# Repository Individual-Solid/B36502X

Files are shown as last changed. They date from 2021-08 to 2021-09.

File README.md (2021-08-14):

# BE6502X-SBC

## Overview
The BE6502X-SBC is an extensible single board computer, based on the "Hello World"
video tutorial by Ben Eater, and the "Potporri" computer design by Garth Wilson.

The computer features a W65c02 8-bit microprocessor running at 1Mhz, 32kb static 
RAM, 32kb EEPROM, two 8-bit GPIO ports, an onboard power supervisor, and a 40-pin
expansion bus.

The computer is "software compatible" with the programs Ben Eater builds in his
Youtube series. 

### Major Differences from the Ben Eater 6502 reference schematic
- Pull-up resistors on all active-low input signals (/NMI, /BE, etc...)
- Proper debounced reset pushbutton and power-on-reset circuit.
- Barrel jack 5v power connector, power LED, reset LED, SYNC LED, and switch.
- All 16 GPIO and 4 Control signals from the VIA are exposed through two
  14-pin shrouded pin IDC headers, CA2 also has an onboard LED.
- LCD, push-buttons, and 8-bit LED output are moved to an expansion board.
- Selector for 65c22 VIAs IRQ pin connection to processor /IRQ or /NMI

### Major Differences from the Garth Wilson 6502 reference schematic
- Clock option chosen is the Can Oscillator. Reset circuit chosen is DS1813.
- Because of these choices, an 74HC00 can be used for address decoding instead 
  of the '132
- Permanently configured for the WDC65c02 processor, 28C256 EEPROM.

## IO Ports
There are two onboard 8-bit IO ports connected to a W65c22S. Each port has an additional
two control lines. Each port has a 14-pin IDC male socket with the following pinout.
|Func|Pin#|Pin#|Func|
|----|-|-|---|
|GND|1|2|5V|
|Px0|3|4|Px1|
|Px2|5|6|Px3|
|Px4|7|8|Px5|
|Px6|9|10|Px7|
|Cx1|11|12|Cx2|
|5V|13|14|GND|

CA2 has an onboard indicator LED, but the pin can easily be repurposed.

## Bus

The BE6502X family sports a 40-pin extension bus. This bus is hardware compatible 
with RC2014 backplanes, although pin assignment is different. There's an existing 
small ecosystem of boards using the "RC6502" bus layout, but I invented my own 
think that felt natural to me. The original RC2014 bus has a lot of Z80/8080 
exclusive signals.

|Pin|BE6502X|RC6502|RC2014|Notes (primarily differences from RC6502)|
|-----|---|---|---|-----|
| 1|A15|A15|A15||
| 2|A14|A14|A14||
| 3|A13|A13|A13||
| 4|A12|A12|A12||
| 5|A11|A11|A11||
| 6|A10|A10|A10||
| 7|A9|A9|A9||
| 8|A8|A8|A8||
| 9|A7|A7|A7||
|10|A6|A6|A6||
|11|A5|A5|A5||
|12|A4|A4|A4||
|13|A3|A3|A3||
|14|A2|A2|A2||
|15|A1|A1|A1||
|16|A0|A0|A0||
|17|GND|GND|GND||
|18|VCC|VCC|VCC||
|19|/MLB|PHI2O|/M1|See CLK for why it's not PHI2O. 6502 has no /M1. This could be SYNC, but /MLB is more interesting for DMA|
|20|/RESET|/RESET|/RESET||
|21|CLK|PHI0I|CLK|Using PHI1 in and PHI2 out is not supported for the new W65c22 chips used in the Eater kit. Just using PHI2 as CLK opens up an additional signal.|
|22|/IRQ|/IRQ|/INT||
|23|/BE|PHI1I (but really,EX0)|/MREQ|Dedicated /BE line for DMA|
|24|RWB|RWB|/WR||
|25|RDY|RDY|/RD||
|26|EX0|SYNC|/IOREQ|SYNC on the bus isn't particularly useful, compared to having an easy EX pin which you can easily connect to /IOEN|
|27|D0|D0|D0||
|28|D1|D1|D1||
|29|D2|D2|D2||
|30|D3|D3|D3||
|31|D4|D4|D4||
|32|D5|D5|D5||
|33|D6|D6|D6||
|34|D7|D7|D7||
|35|SDA|Tx|Tx|Putting the UART lines on the bus isn't particularly useful. I'm not aware of any meaningful uses where another module wanted the primary UART.|
|36|SCL|Rx|Rx|So instead, these are dedicated for I2C devices. There's no I2C master on the SBC, but there's also not a UART.|
|37|/NMI|/NMI|U1||
|38|EX1|EX1|U2||
|39|EX2|EX2|U3||
|40|GND|EX3|U4|Another GND line never hurt anyone.|

Next to the bus on the mainboard (Garth-1 based) are jumpers for the following signals, allowing
easy assignment to an EX line on the Bus, or for direct jumping to another board.

|Pin|Signal|
|-|-|
|1|SYNC|
|2|/VP|
|3|/RAMSEL|
|4|/IOSEL|

## Expansion Cards

Expansion cards connect to the BE6502X bus, with the exception of the Eater Experiment
card, which connects directly to the IO Ports! These are all the hopes and dreams and 
not yet designed.

### Dual IO and UART
2nd 65c22 VIA, 65c51 UART

### Arduino Mega Bus Monitor
Connect an Arduino Mega 2560 to monitor the bus and provide a low speed clock. Can
also use the Mega as a RAM Programmer/"bootloader".

### Ben Eater Experiment Card
Uses the IO Port A&B 14-pin connectors, adds a 2x20 LCD display and five push
buttons. A jumper is provided for 4-bit or 8-bit mode on the LCD, and the
push buttons are wire-OR'd together to CA1 for optional interrupt control.
Both the screen contrast and backlight are adjustable by onboard potentiometers.

## References
- RC6502 Bus design notes (and related subjects). https://github.com/tebl/RC6502-Apple-1-Replica/blob/master/Bus.md
- Ben Eater "Hello World" series home with schematic and videos. https://eater.net/6502
- Garth Wilson's 6502 Primer, including "Potporri" schematic, and countless other useful references. https://wilsonminesco.com/6502primer/potpourri.html#BAS_CPU
- Stephen Cousin's "Small Computer Central" with design notes on RC2014 backplanes, and a good source of the SC141 modular backplane and the SC142 Power Supply Module. https://smallcomputercentral.wordpress.com/kits/

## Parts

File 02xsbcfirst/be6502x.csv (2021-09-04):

Source: | C:\Users\cdcar\Desktop\kicad\b36502x\be6502x\be6502x.sch
Date: | 8/14/2021 1:05:58 PM
Tool: | Eeschema (5.1.10)-1
Component Count: | 44
Ref | Value | Footprint | Datasheet | Manufacturer | Vendor
C1 | 100uf | Capacitor_THT:CP_Radial_D4.0mm_P2.00mm | ~
C2 | .01uf | Capacitor_THT:C_Disc_D3.0mm_W2.0mm_P2.50mm | ~
C3 | .01uf | Capacitor_THT:C_Disc_D3.0mm_W2.0mm_P2.50mm | ~
C4 | .01uf | Capacitor_THT:C_Disc_D3.0mm_W2.0mm_P2.50mm | ~
C5 | .01uf | Capacitor_THT:C_Disc_D3.0mm_W2.0mm_P2.50mm | ~
C6 | .01uf | Capacitor_THT:C_Disc_D3.0mm_W2.0mm_P2.50mm | ~
C7 | .01uf | Capacitor_THT:C_Disc_D3.0mm_W2.0mm_P2.50mm | ~
C8 | .01uf | Capacitor_THT:C_Disc_D3.0mm_W2.0mm_P2.50mm | ~
C9 | .01uf | Capacitor_THT:C_Disc_D3.0mm_W2.0mm_P2.50mm | ~
C10 | .01uf | Capacitor_THT:C_Disc_D3.0mm_W2.0mm_P2.50mm | ~
C11 | .01uf | Capacitor_THT:C_Disc_D3.0mm_W2.0mm_P2.50mm | ~
D1 | PWR LED | LED_THT:LED_D4.0mm | ~
D2 | CA1 LED | LED_THT:LED_D4.0mm | ~
D3 | SYNC LED | LED_THT:LED_D4.0mm | ~
D4 | RESET LED | LED_THT:LED_D4.0mm | ~
J0 | Regulated +5v In | Connector_BarrelJack:BarrelJack_Horizontal | ~
J1 | IO Port A | Connector_IDC:IDC-Header_2x07_P2.54mm_Vertical | ~
J2 | IO Port B | Connector_IDC:IDC-Header_2x07_P2.54mm_Vertical | ~
J3 | Unassigned Bus Signals | Connector_PinSocket_2.54mm:PinSocket_1x05_P2.54mm_Vertical | ~
J4 | Control Signals | Connector_PinHeader_2.54mm:PinHeader_1x04_P2.54mm_Vertical | ~
JP1 | I2C Pullups | Jumper:SolderJumper-2_P1.3mm_Bridged_Pad1.0x1.5mm | ~
JP2 | VIA IRQ Select | Connector_PinHeader_2.54mm:PinHeader_1x03_P2.54mm_Vertical | ~
JP3 | I2C Pullups | Jumper:SolderJumper-2_P1.3mm_Bridged_Pad1.0x1.5mm | ~
P1 | BE6502X Bus | Connector_PinSocket_2.54mm:PinSocket_1x40_P2.54mm_Vertical | ~
P2 | BE6502X Bus | Connector_PinSocket_2.54mm:PinSocket_1x40_P2.54mm_Vertical | ~
P3 | BE6502X Bus | Connector_PinSocket_2.54mm:PinSocket_1x40_P2.54mm_Vertical | ~
R1 | 3.3k | Resistor_THT:R_Axial_DIN0207_L6.3mm_D2.5mm_P7.62mm_Horizontal | ~
R2 | 3.3k | Resistor_THT:R_Axial_DIN0207_L6.3mm_D2.5mm_P7.62mm_Horizontal | ~
R3 | 10k | Resistor_THT:R_Axial_DIN0207_L6.3mm_D2.5mm_P7.62mm_Horizontal | ~
R4 | 10k | Resistor_THT:R_Axial_DIN0207_L6.3mm_D2.5mm_P7.62mm_Horizontal | ~
R5 | 10k | Resistor_THT:R_Axial_DIN0207_L6.3mm_D2.5mm_P7.62mm_Horizontal | ~
R6 | 10k | Resistor_THT:R_Axial_DIN0207_L6.3mm_D2.5mm_P7.62mm_Horizontal | ~
R7 | 3.3k | Resistor_THT:R_Axial_DIN0207_L6.3mm_D2.5mm_P7.62mm_Horizontal | ~
R8 | 3.3k | Resistor_THT:R_Axial_DIN0207_L6.3mm_D2.5mm_P7.62mm_Horizontal | ~
R9 | 4.7k | Resistor_THT:R_Axial_DIN0207_L6.3mm_D2.5mm_P7.62mm_Horizontal | ~
R10 | 4.7k | Resistor_THT:R_Axial_DIN0207_L6.3mm_D2.5mm_P7.62mm_Horizontal | ~
SW1 | Reset | Button_Switch_THT:SW_PUSH_6mm | ~
U1 | W65C02SxP | Package_DIP:DIP-40_W15.24mm_Socket | http://www.westerndesigncenter.com/wdc/documentation/w65c02s.pdf
U2 | DS1813 | Package_TO_SOT_THT:TO-92 | https://datasheets.maximintegrated.com/en/ds/DS1813.pdf
U3 | 74HC00 | Package_DIP:DIP-14_W7.62mm_Socket | http://www.ti.com/lit/gpn/sn74hc00
U4 | 28C256 | Socket:DIP_Socket-28_W11.9_W12.7_W15.24_W17.78_W18.5_3M_228-1277-00-0602J | http://ww1.microchip.com/downloads/en/DeviceDoc/doc0006.pdf
U5 | KM62256CLP | Package_DIP:DIP-28_W15.24mm_Socket | https://www.futurlec.com/Datasheet/Memory/62256.pdf
U6 | W65C22SxP | Package_DIP:DIP-40_W15.24mm_Socket | http://www.westerndesigncenter.com/wdc/documentation/w65c22.pdf
X1 | 1MHz | Oscillator:Oscillator_DIP-14 | http://cdn-https://www.jameco.com/Jameco/Products/ProdDS/27861.pdf

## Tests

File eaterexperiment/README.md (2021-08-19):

# Eater Experiment Board

The Eater Experiment Board connects to the two IO Ports on the BE6502x SBC, and
breaks out LEDS, buttons, and a header for a 2x20 character LCD. This board lets
you run all the 6522 example code on Ben Eater's 6502 project website, AND has
extra LEDs and buttons connected for additional experimenting.

This is a very simple board, with only one "configuration" option. There's a 
jumper to select whether the LCD should be in normal 8-bit mode, or have all
of its IO on Port B, using 4-bit mode. 

UGH EVERYTHING HERE ON SUX.Plug in both IDC cables, select your mode,
attach the LCD, and you're ready to go.

Both IO Ports have indicator LEDs on all 8 bidirectional data lines as well as
both control lines. That's a total of 20 blinkenable-lites! The ten signals 
that compose port A also have input pushbuttons (tied high, push closes it to
ground). This makes this a great board for prototyping input devices or doing
the same experiments as in Ben's youtube videos.

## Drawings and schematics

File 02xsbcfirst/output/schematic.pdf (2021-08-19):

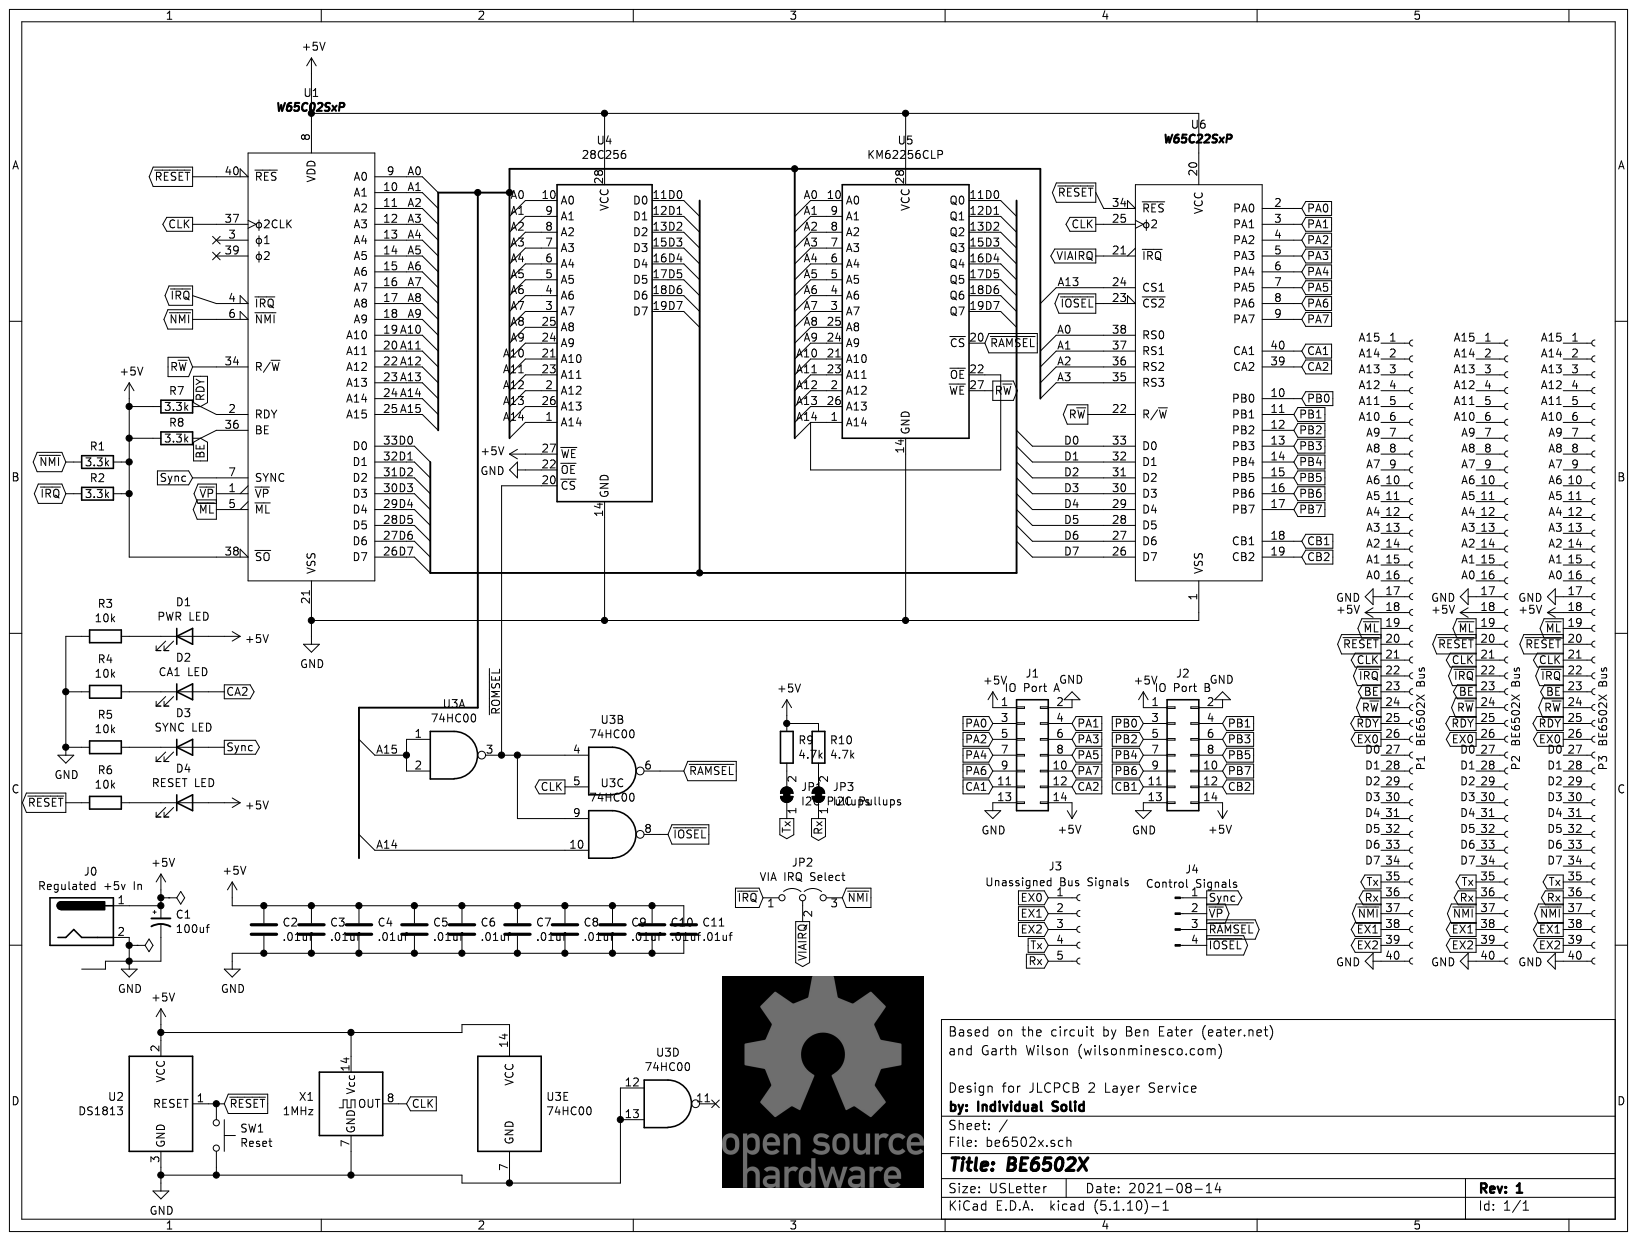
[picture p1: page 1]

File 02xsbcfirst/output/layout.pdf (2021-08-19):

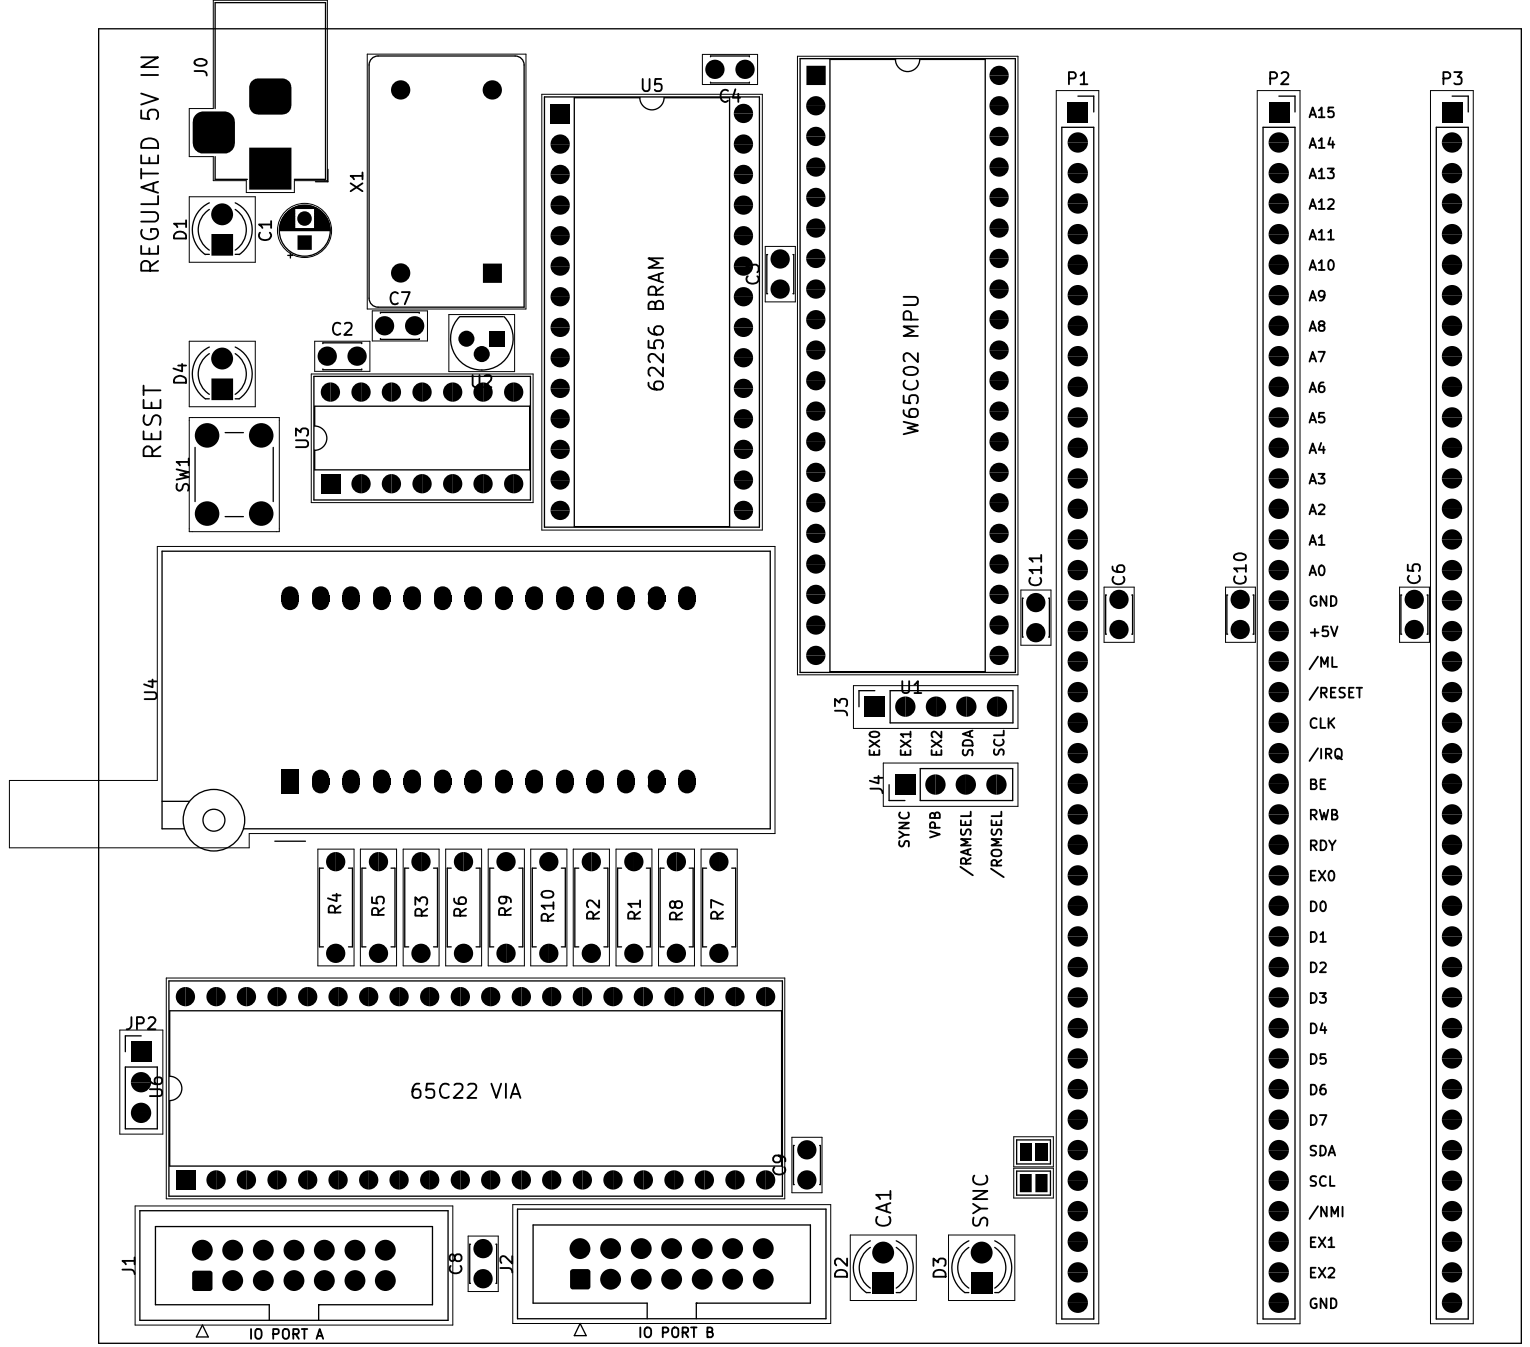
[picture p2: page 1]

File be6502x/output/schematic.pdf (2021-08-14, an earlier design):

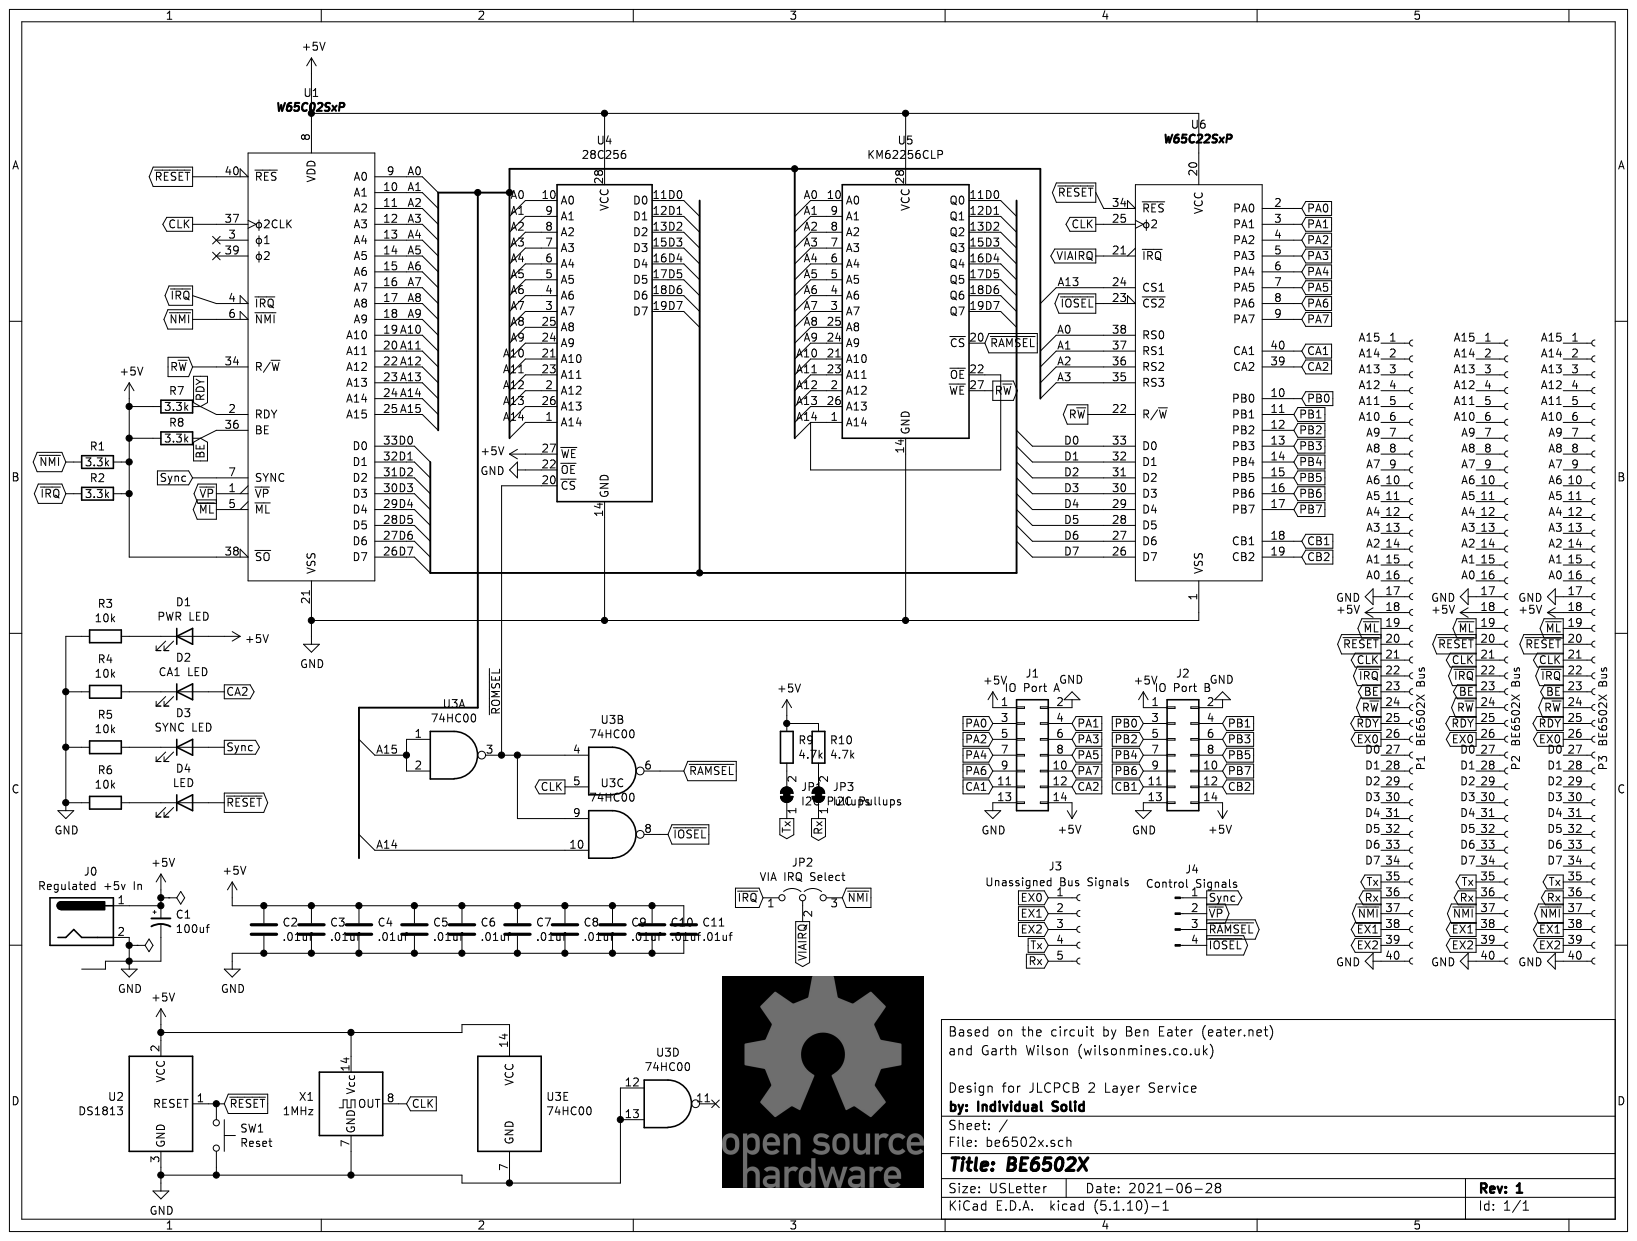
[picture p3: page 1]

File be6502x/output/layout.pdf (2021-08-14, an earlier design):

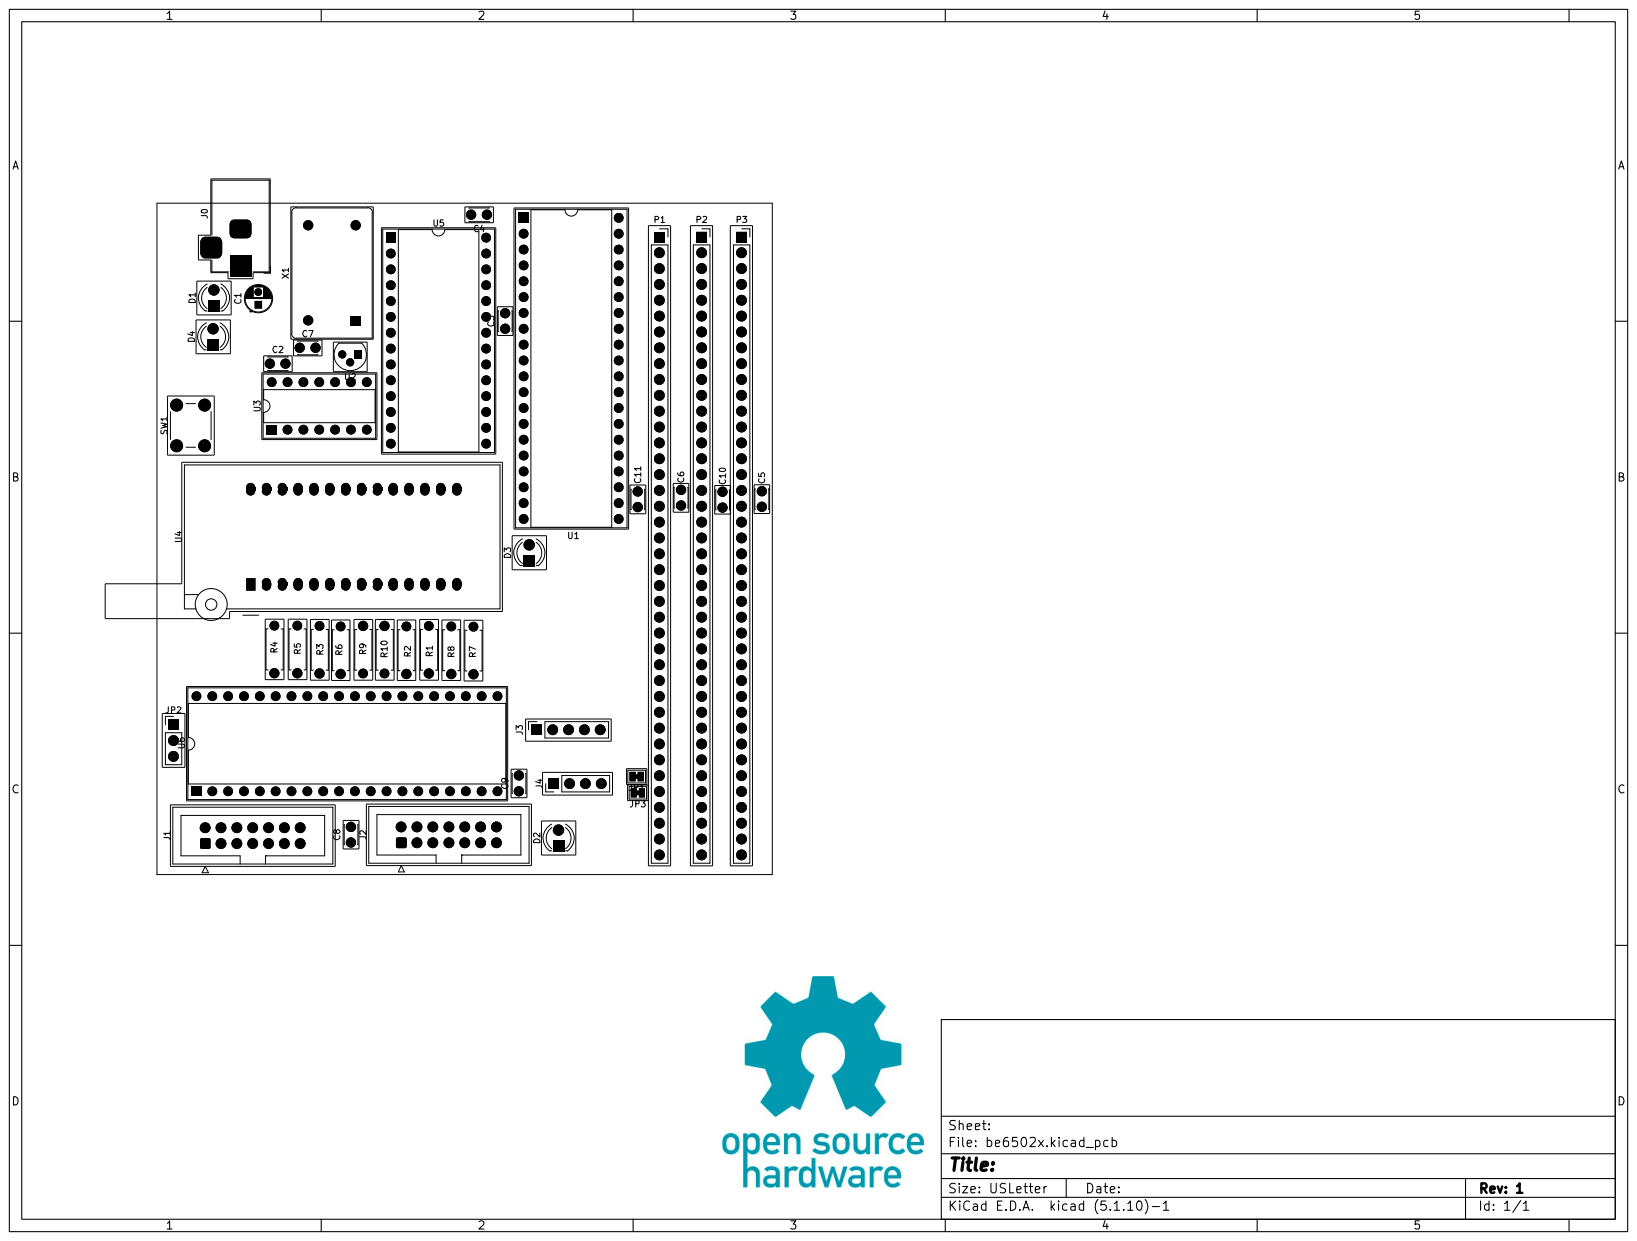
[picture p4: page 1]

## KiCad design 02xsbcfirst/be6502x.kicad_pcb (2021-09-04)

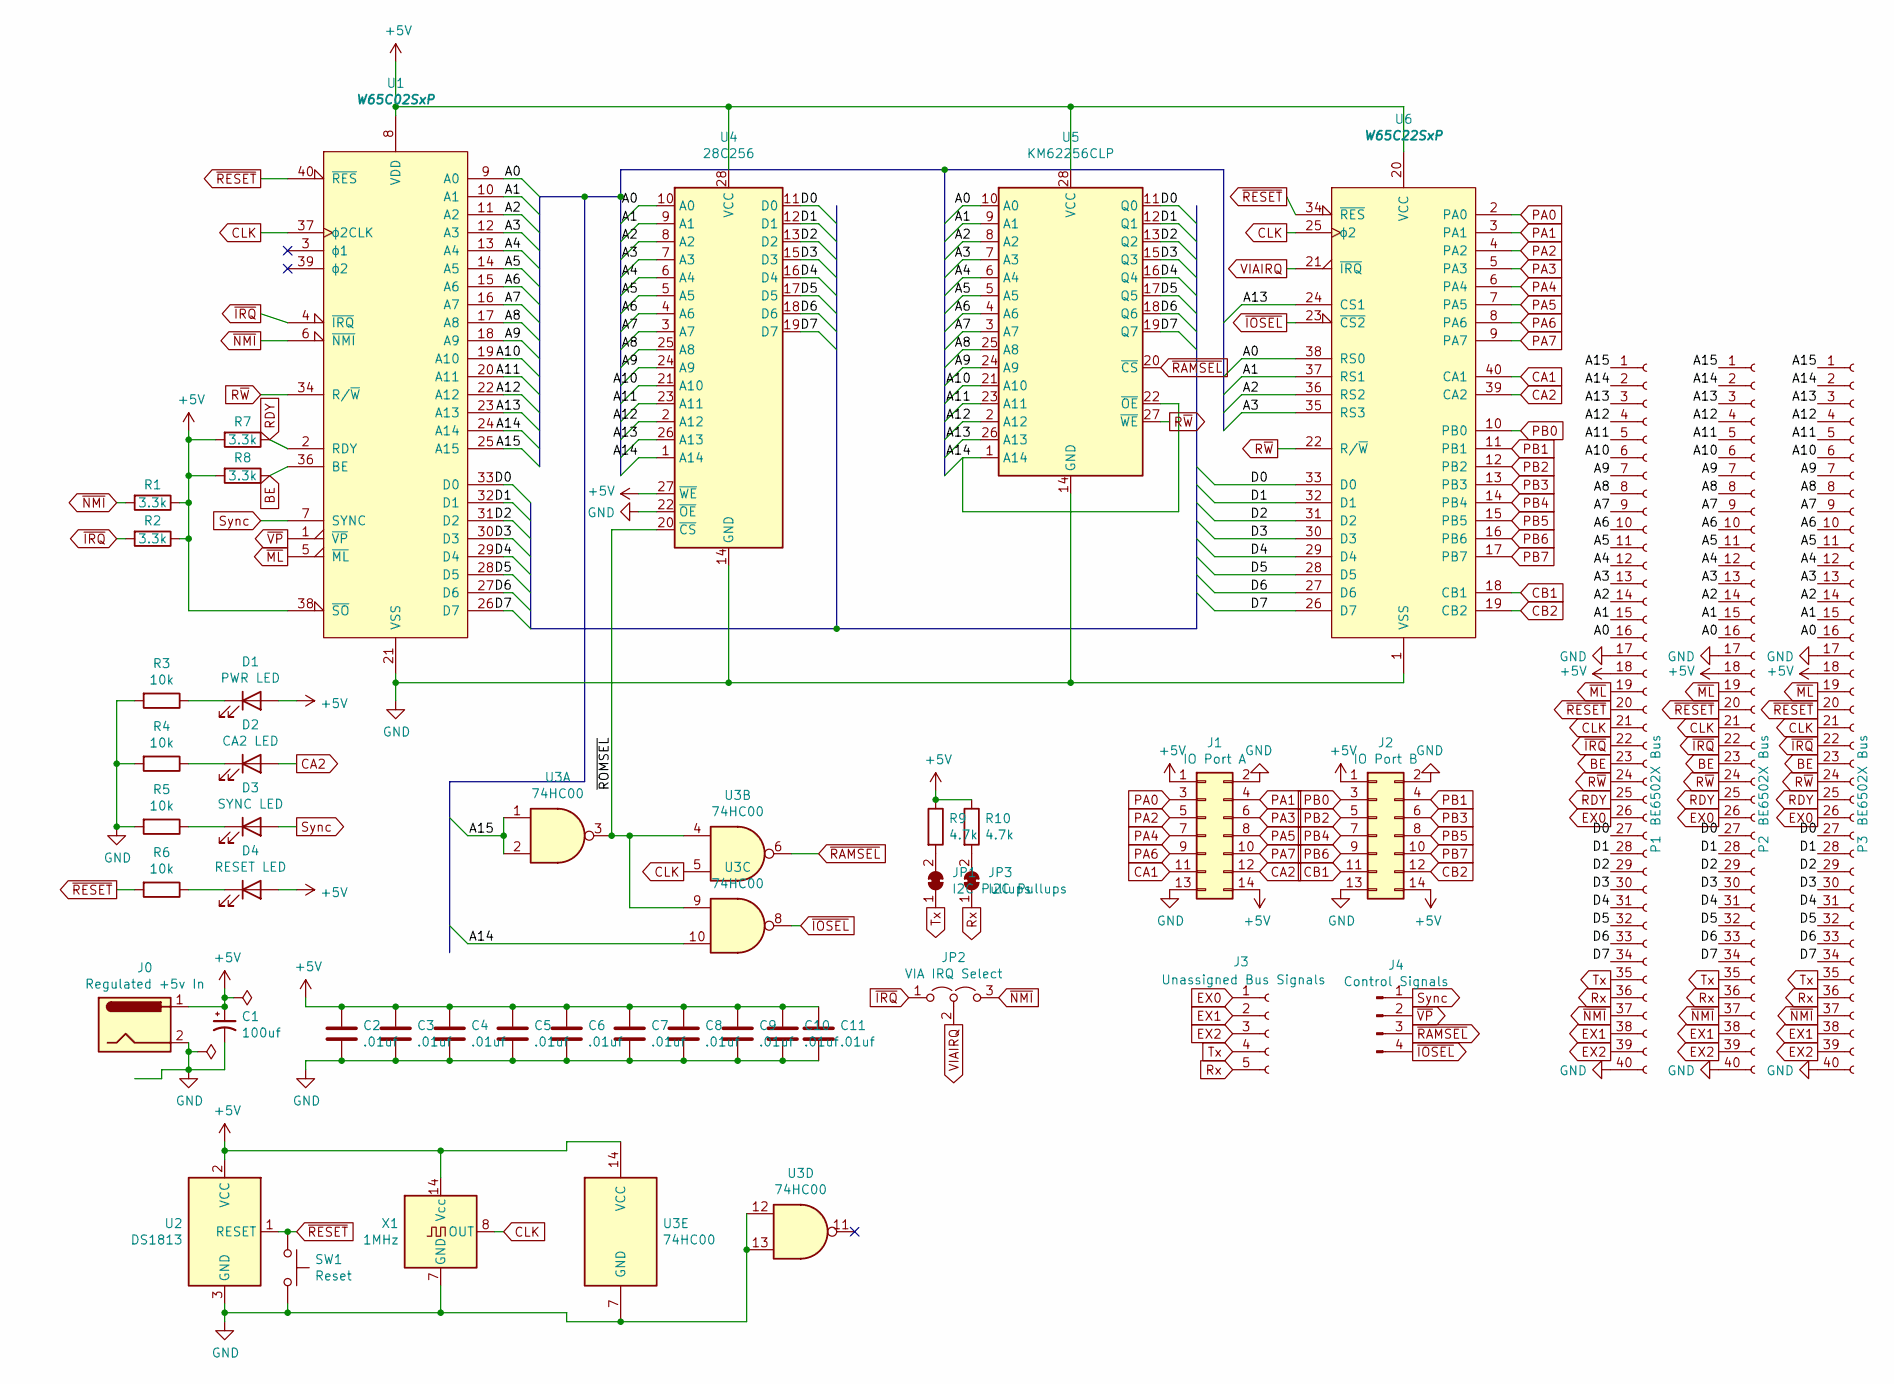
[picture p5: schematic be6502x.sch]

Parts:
C1: 100uf; CP_Radial_D4.0mm_P2.00mm
C2, C3, C4, C5, C6, C7, C8, C9, C10, C11: .01uf; C_Disc_D3.0mm_W2.0mm_P2.50mm
D1: PWR LED; LED_D4.0mm
D2: CA2 LED; LED_D4.0mm
D3: SYNC LED; LED_D4.0mm
D4: RESET LED; LED_D4.0mm
J0: Regulated +5v In; BarrelJack_Horizontal
J1: IO Port A; IDC-Header_2x07_P2.54mm_Vertical
J2: IO Port B; IDC-Header_2x07_P2.54mm_Vertical
J3: Unassigned Bus Signals; PinSocket_1x05_P2.54mm_Vertical
J4: Control Signals; PinHeader_1x04_P2.54mm_Vertical
JP1, JP3: I2C Pullups; SolderJumper-2_P1.3mm_Bridged_Pad1.0x1.5mm
JP2: VIA IRQ Select; PinHeader_1x03_P2.54mm_Vertical
P1, P2, P3: BE6502X Bus; PinSocket_1x40_P2.54mm_Vertical
R1, R2, R7, R8: 3.3k; R_Axial_DIN0207_L6.3mm_D2.5mm_P7.62mm_Horizontal
R3, R4, R5, R6: 10k; R_Axial_DIN0207_L6.3mm_D2.5mm_P7.62mm_Horizontal
R9, R10: 4.7k; R_Axial_DIN0207_L6.3mm_D2.5mm_P7.62mm_Horizontal
SW1: Reset; SW_PUSH_6mm
U1: W65C02SxP; DIP-40_W15.24mm_Socket
U2: DS1813; TO-92
U3: 74HC00; DIP-14_W7.62mm_Socket
U4: 28C256; DIP_Socket-28_W11.9_W12.7_W15.24_W17.78_W18.5_3M_228-1277-0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
U5: KM62256CLP; DIP-28_W15.24mm_Socket
U6: W65C22SxP; DIP-40_W15.24mm_Socket
X1: 1MHz; Oscillator_DIP-14

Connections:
+5V: C1.1, C2.1, C3.1, C4.1, C5.1, C6.1, C7.1, C8.1, C9.1, C10.1, C11.1, D1.2 (A), D4.2 (A), J0.1, J1.1, J1.14, J2.1, J2.14, P1.18, P2.18, P3.18, R1.1, R2.1, R7.2, R8.2, R9.1, R10.1, U1.8 (VDD), U1.38 (~SO), U2.2 (VCC), U3.14 (VCC), U4.27 (~WE), U4.28 (VCC), U5.28 (VCC), U6.20 (VCC), X1.14 (Vcc)
/A0: P1.16, P2.16, P3.16, U1.9 (A0), U4.10 (A0), U5.10 (A0), U6.38 (RS0)
/A1: P1.15, P2.15, P3.15, U1.10 (A1), U4.9 (A1), U5.9 (A1), U6.37 (RS1)
/A2: P1.14, P2.14, P3.14, U1.11 (A2), U4.8 (A2), U5.8 (A2), U6.36 (RS2)
/A3: P1.13, P2.13, P3.13, U1.12 (A3), U4.7 (A3), U5.7 (A3), U6.35 (RS3)
/A4: P1.12, P2.12, P3.12, U1.13 (A4), U4.6 (A4), U5.6 (A4)
/A5: P1.11, P2.11, P3.11, U1.14 (A5), U4.5 (A5), U5.5 (A5)
/A6: P1.10, P2.10, P3.10, U1.15 (A6), U4.4 (A6), U5.4 (A6)
/A7: P1.9, P2.9, P3.9, U1.16 (A7), U4.3 (A7), U5.3 (A7)
/A8: P1.8, P2.8, P3.8, U1.17 (A8), U4.25 (A8), U5.25 (A8)
/A9: P1.7, P2.7, P3.7, U1.18 (A9), U4.24 (A9), U5.24 (A9)
/A10: P1.6, P2.6, P3.6, U1.19 (A10), U4.21 (A10), U5.21 (A10)
/A11: P1.5, P2.5, P3.5, U1.20 (A11), U4.23 (A11), U5.23 (A11)
/A12: P1.4, P2.4, P3.4, U1.22 (A12), U4.2 (A12), U5.2 (A12)
/A13: P1.3, P2.3, P3.3, U1.23 (A13), U4.26 (A13), U5.26 (A13), U6.24 (CS1)
/A14: P1.2, P2.2, P3.2, U1.24 (A14), U3.10, U4.1 (A14), U5.1 (A14), U5.22 (~OE)
/A15: P1.1, P2.1, P3.1, U1.25 (A15), U3.1, U3.2
/D0: P1.27, P2.27, P3.27, U1.33 (D0), U4.11 (D0), U5.11 (Q0), U6.33 (D0)
/D1: P1.28, P2.28, P3.28, U1.32 (D1), U4.12 (D1), U5.12 (Q1), U6.32 (D1)
/D2: P1.29, P2.29, P3.29, U1.31 (D2), U4.13 (D2), U5.13 (Q2), U6.31 (D2)
/D3: P1.30, P2.30, P3.30, U1.30 (D3), U4.15 (D3), U5.15 (Q3), U6.30 (D3)
/D4: P1.31, P2.31, P3.31, U1.29 (D4), U4.16 (D4), U5.16 (Q4), U6.29 (D4)
/D5: P1.32, P2.32, P3.32, U1.28 (D5), U4.17 (D5), U5.17 (Q5), U6.28 (D5)
/D6: P1.33, P2.33, P3.33, U1.27 (D6), U4.18 (D6), U5.18 (Q6), U6.27 (D6)
/D7: P1.34, P2.34, P3.34, U1.26 (D7), U4.19 (D7), U5.19 (Q7), U6.26 (D7)
/~ROMSEL~: U3.3, U3.4, U3.9, U4.20 (~CS)
BE: P1.23, P2.23, P3.23, R8.1, U1.36 (BE)
CA1: J1.11, U6.40 (CA1)
CA2: D2.2 (A), J1.12, U6.39 (CA2)
CB1: J2.11, U6.18 (CB1)
CB2: J2.12, U6.19 (CB2)
CLK: P1.21, P2.21, P3.21, U1.37 (ϕ2CLK), U3.5, U6.25 (ϕ2), X1.8 (OUT)
EX0: J3.1, P1.26, P2.26, P3.26
EX1: J3.2, P1.38, P2.38, P3.38
EX2: J3.3, P1.39, P2.39, P3.39
GND: C1.2, C2.2, C3.2, C4.2, C5.2, C6.2, C7.2, C8.2, C9.2, C10.2, C11.2, J0.2, J1.2, J1.13, J2.2, J2.13, P1.17, P1.40, P2.17, P2.40, P3.17, P3.40, R3.2, R4.2, R5.2, SW1.2, U1.21 (VSS), U2.3 (GND), U3.7 (GND), U3.12, U3.13, U4.14 (GND), U4.22 (~OE), U5.14 (GND), U6.1 (VSS), X1.7 (GND)
unnamed: D1.1 (K), R3.1
unnamed: D2.1 (K), R4.1
unnamed: D3.1 (K), R5.1
unnamed: D4.1 (K), R6.1
unnamed: JP1.2 (B), R9.2
unnamed: JP3.2 (B), R10.2
PA0: J1.3, U6.2 (PA0)
PA1: J1.4, U6.3 (PA1)
PA2: J1.5, U6.4 (PA2)
PA3: J1.6, U6.5 (PA3)
PA4: J1.7, U6.6 (PA4)
PA5: J1.8, U6.7 (PA5)
PA6: J1.9, U6.8 (PA6)
PA7: J1.10, U6.9 (PA7)
PB0: J2.3, U6.10 (PB0)
PB1: J2.4, U6.11 (PB1)
PB2: J2.5, U6.12 (PB2)
PB3: J2.6, U6.13 (PB3)
PB4: J2.7, U6.14 (PB4)
PB5: J2.8, U6.15 (PB5)
PB6: J2.9, U6.16 (PB6)
PB7: J2.10, U6.17 (PB7)
RDY: P1.25, P2.25, P3.25, R7.1, U1.2 (RDY)
Rx: J3.5, JP3.1 (A), P1.36, P2.36, P3.36
R~W~: P1.24, P2.24, P3.24, U1.34 (R/~W), U5.27 (~WE), U6.22 (R/~W)
Sync: D3.2 (A), J4.1, U1.7 (SYNC)
Tx: J3.4, JP1.1 (A), P1.35, P2.35, P3.35
VIAIRQ: JP2.2 (C), U6.21 (~IRQ)
~IOSEL~: J4.4, U3.8, U6.23 (~CS2)
~IRQ~: JP2.1 (A), P1.22, P2.22, P3.22, R2.2, U1.4 (~IRQ)
~ML~: P1.19, P2.19, P3.19, U1.5 (~ML)
~NMI~: JP2.3 (B), P1.37, P2.37, P3.37, R1.2, U1.6 (~NMI)
~RAMSEL~: J4.3, U3.6, U5.20 (~CS)
~RESET~: P1.20, P2.20, P3.20, R6.2, SW1.1, U1.40 (~RES), U2.1 (RESET), U6.34 (~RES)
~VP~: J4.2, U1.1 (~VP)

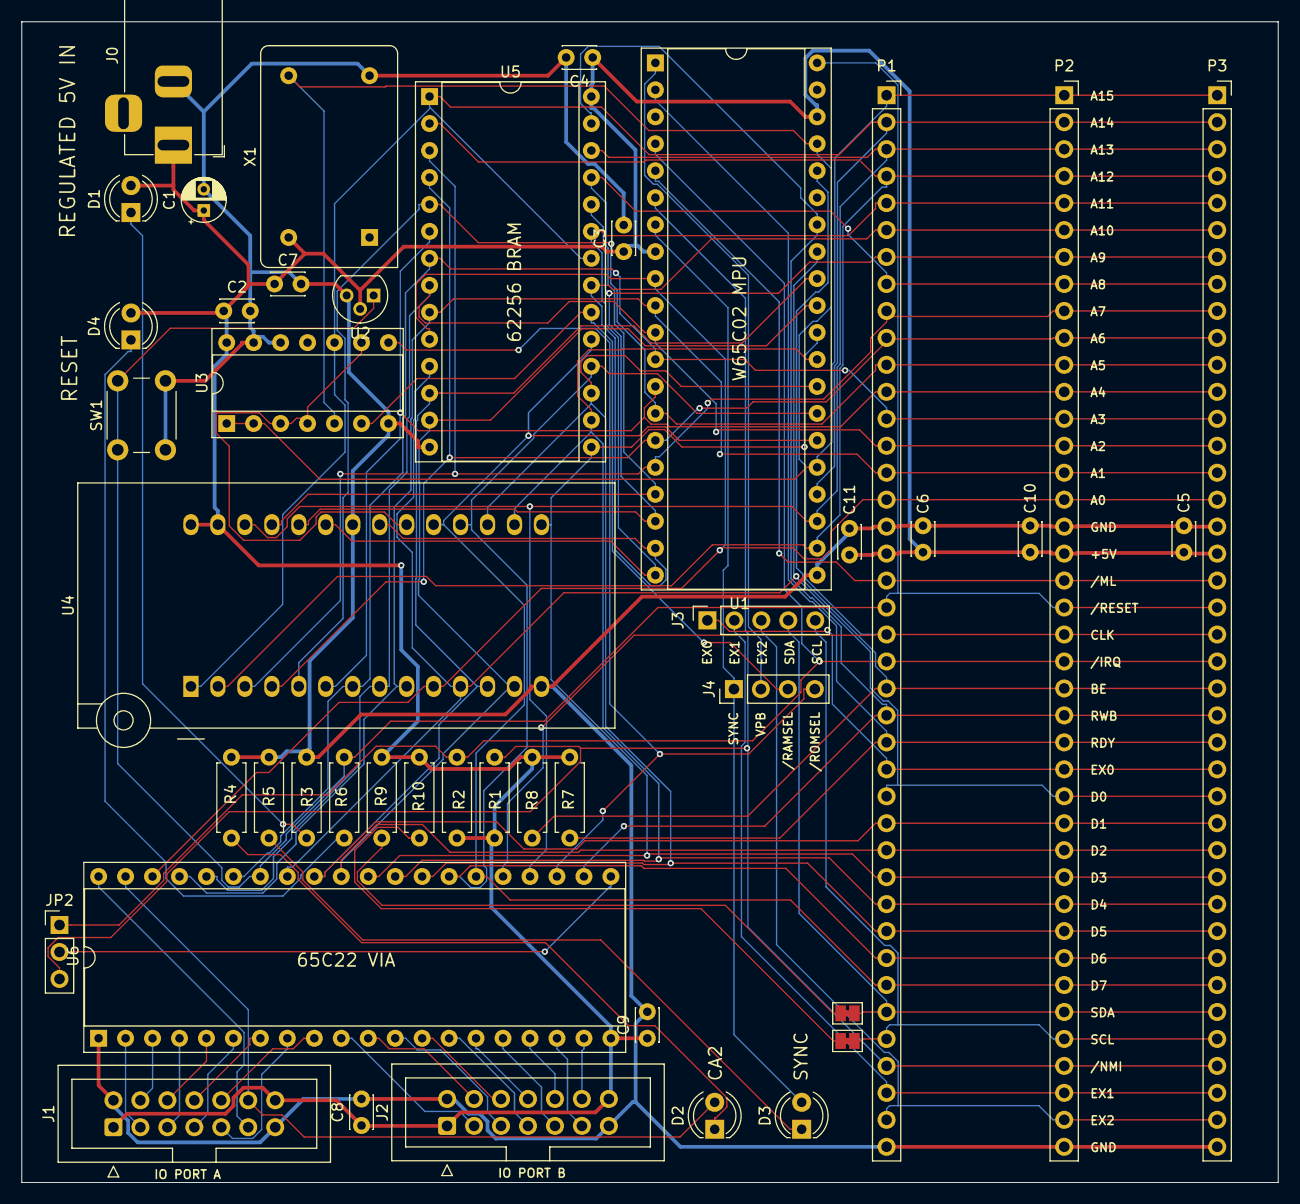
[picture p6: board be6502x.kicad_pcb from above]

Board: 2 copper layers, 118.4 x 109.3 mm, 44 parts (0 on the bottom side), 71 nets.

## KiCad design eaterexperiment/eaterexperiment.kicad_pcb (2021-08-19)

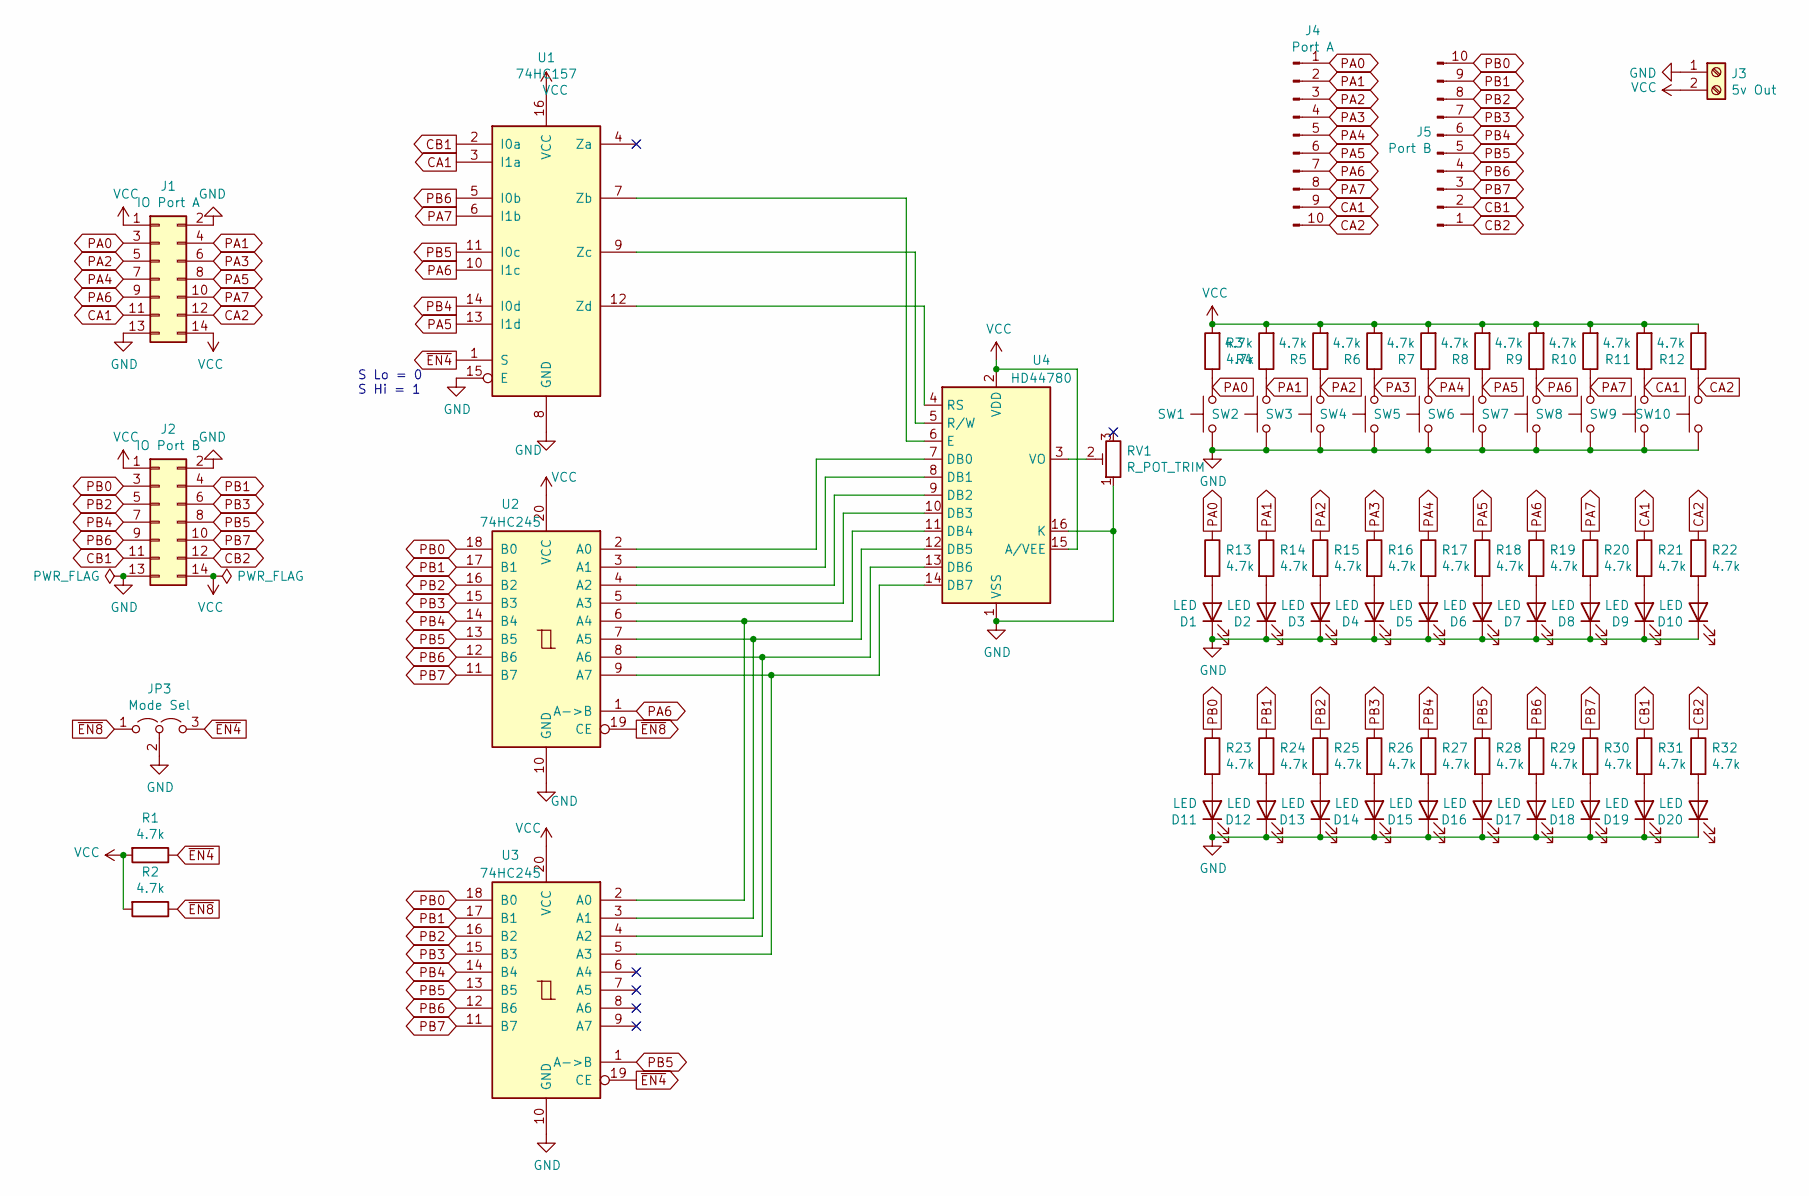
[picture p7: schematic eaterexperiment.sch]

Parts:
D1, D2, D3, D4, D5, D6, D7, D8, D9, D10, D11, D12, D13, D14, D15, D16, D17, D18, D19, D20: LED; LED_0805_2012Metric; JLCPCB C2297
J1: IO Port A; PinHeader_2x07_P2.54mm_Horizontal
J2: IO Port B; PinHeader_2x07_P2.54mm_Horizontal
J3: 5v Out; TerminalBlock_bornier-2_P5.08mm
J4: Port A; PinHeader_1x10_P2.54mm_Horizontal
J5: Port B; PinHeader_1x10_P2.54mm_Horizontal
JP3: Mode Sel; PinHeader_1x03_P2.54mm_Vertical
R1, R2, R3, R4, R5, R6, R7, R8, R9, R10, R11, R12, R13, R14, R15, R16, R17, R18, R19, R20, R21, R22, R23, R24, R25, R26, R27, R28, R29, R30, R31, R32: 4.7k; R_0603_1608Metric; JLCPCB C23162
RV1: R_POT_TRIM; Potentiometer_Bourns_3266Y_Vertical
SW1, SW2, SW3, SW4, SW5, SW6, SW7, SW8, SW9, SW10: Push; SW_Push_1P1T_NO_CK_KSC6xxJ; JLCPCB C318884
U1: 74HC157; HTSSOP-16-1EP_4.4x5mm_P0.65mm_EP3.4x5mm; JLCPCB C148201
U2, U3: 74HC245; SOIC-20W_7.5x12.8mm_P1.27mm; JLCPCB C5625
U4: HD44780; PinSocket_1x16_P2.54mm_Vertical

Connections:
CA1: J1.11, J4.9, R21.1, U1.3 (I1a)
CA2: J1.12, J4.10, R22.1
CB1: J2.11, J5.2, R31.1, U1.2 (I0a)
CB2: J2.12, J5.1, R32.1
GND: D1.1 (K), D2.1 (K), D3.1 (K), D4.1 (K), D5.1 (K), D6.1 (K), D7.1 (K), D8.1 (K), D9.1 (K), D10.1 (K), D11.1 (K), D12.1 (K), D13.1 (K), D14.1 (K), D15.1 (K), D16.1 (K), D17.1 (K), D18.1 (K), D19.1 (K), D20.1 (K), J1.2, J1.13, J2.2, J2.13, J3.1, JP3.2 (C), RV1.1, SW1.1, SW2.1, SW3.1, SW4.1, SW5.1, SW6.1, SW7.1, SW8.1, SW9.1, SW10.1, U1.8 (GND), U1.15 (E), U2.10 (GND), U3.10 (GND), U4.1 (VSS), U4.16 (K)
unnamed: D1.2 (A), R13.2
unnamed: D2.2 (A), R14.2
unnamed: D3.2 (A), R15.2
unnamed: D4.2 (A), R16.2
unnamed: D5.2 (A), R17.2
unnamed: D6.2 (A), R18.2
unnamed: D7.2 (A), R19.2
unnamed: D8.2 (A), R20.2
unnamed: D9.2 (A), R21.2
unnamed: D10.2 (A), R22.2
unnamed: D11.2 (A), R23.2
unnamed: D12.2 (A), R24.2
unnamed: D13.2 (A), R25.2
unnamed: D14.2 (A), R26.2
unnamed: D15.2 (A), R27.2
unnamed: D16.2 (A), R28.2
unnamed: D17.2 (A), R29.2
unnamed: D18.2 (A), R30.2
unnamed: D19.2 (A), R31.2
unnamed: D20.2 (A), R32.2
unnamed: R3.1, SW1.2
unnamed: R4.1, SW2.2
unnamed: R5.1, SW3.2
unnamed: R6.1, SW4.2
unnamed: R7.1, SW5.2
unnamed: R8.1, SW6.2
unnamed: R9.1, SW7.2
unnamed: R10.1, SW8.2
unnamed: R11.1, SW9.2
unnamed: R12.1, SW10.2
unnamed: RV1.2, U4.3 (VO)
unnamed: U1.7 (Zb), U4.6 (E)
unnamed: U1.9 (Zc), U4.5 (R/W)
unnamed: U1.12 (Zd), U4.4 (RS)
unnamed: U2.2 (A0), U4.7 (DB0)
unnamed: U2.3 (A1), U4.8 (DB1)
unnamed: U2.4 (A2), U4.9 (DB2)
unnamed: U2.5 (A3), U4.10 (DB3)
unnamed: U2.6 (A4), U3.2 (A0), U4.11 (DB4)
unnamed: U2.7 (A5), U3.3 (A1), U4.12 (DB5)
unnamed: U2.8 (A6), U3.4 (A2), U4.13 (DB6)
unnamed: U2.9 (A7), U3.5 (A3), U4.14 (DB7)
PA0: J1.3, J4.1, R13.1
PA1: J1.4, J4.2, R14.1
PA2: J1.5, J4.3, R15.1
PA3: J1.6, J4.4, R16.1
PA4: J1.7, J4.5, R17.1
PA5: J1.8, J4.6, R18.1, U1.13 (I1d)
PA6: J1.9, J4.7, R19.1, U1.10 (I1c), U2.1 (A->B)
PA7: J1.10, J4.8, R20.1, U1.6 (I1b)
PB0: J2.3, J5.10, R23.1, U2.18 (B0), U3.18 (B0)
PB1: J2.4, J5.9, R24.1, U2.17 (B1), U3.17 (B1)
PB2: J2.5, J5.8, R25.1, U2.16 (B2), U3.16 (B2)
PB3: J2.6, J5.7, R26.1, U2.15 (B3), U3.15 (B3)
PB4: J2.7, J5.6, R27.1, U1.14 (I0d), U2.14 (B4), U3.14 (B4)
PB5: J2.8, J5.5, R28.1, U1.11 (I0c), U2.13 (B5), U3.1 (A->B), U3.13 (B5)
PB6: J2.9, J5.4, R29.1, U1.5 (I0b), U2.12 (B6), U3.12 (B6)
PB7: J2.10, J5.3, R30.1, U2.11 (B7), U3.11 (B7)
VCC: J1.1, J1.14, J2.1, J2.14, J3.2, R1.2, R2.2, R3.2, R4.2, R5.2, R6.2, R7.2, R8.2, R9.2, R10.2, R11.2, R12.2, U1.16 (VCC), U2.20 (VCC), U3.20 (VCC), U4.2 (VDD), U4.15 (A/VEE)
~EN4~: JP3.3 (B), R1.1, U1.1 (S), U3.19 (CE)
~EN8~: JP3.1 (A), R2.1, U2.19 (CE)

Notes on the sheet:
S Lo = 0 S Hi = 1

Board: 2 copper layers, 73 parts (0 on the bottom side), 66 nets, no tracks yet.
